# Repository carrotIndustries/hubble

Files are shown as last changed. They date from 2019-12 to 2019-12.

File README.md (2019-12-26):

Hubble is a multitool for SFP(+) transceivers. It can read 
identification and monitoring data using the transceiver's I²C-based 
management interface.

This project is still work in progress.

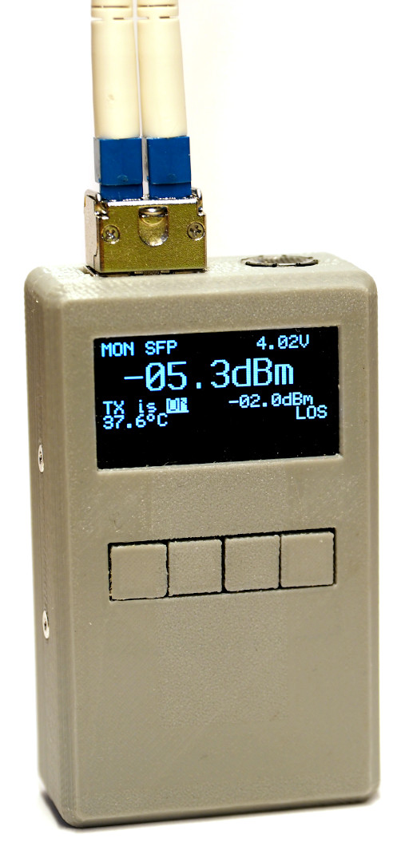
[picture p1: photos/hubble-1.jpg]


# Features and Facts
- Read SFP(+) transceiver identification data
- Optical transceivers
  - turn laser on/off
  - read optical power (RX and TX)
  - read temperature
- 88E111 based 1000 BASE-T transceivers
  - Detect link
  - Count received frames
  - Cable test (TDR) (work in progress)
- (optionally) PRBS generator and eye diagram monitor (work in progress)
- STM32L412 Cortex-M4 MCU
- 128x64 monochrome OLED
- 4 buttons (Mode, Select, Down, Up)
- USB 2.0 Fullspeed for charging and software upgrade
- 14500 Li-Ion battery
- really bright LED flashlight

# Hardware

## Main board

[Schematics](hw/main/output/schematic.pdf)

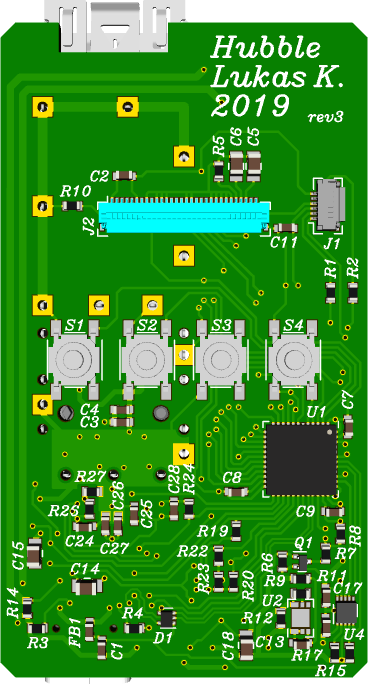
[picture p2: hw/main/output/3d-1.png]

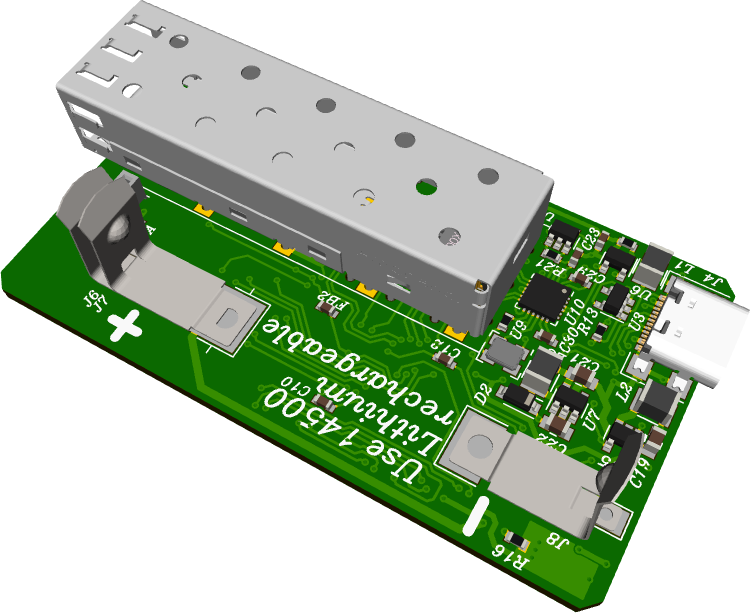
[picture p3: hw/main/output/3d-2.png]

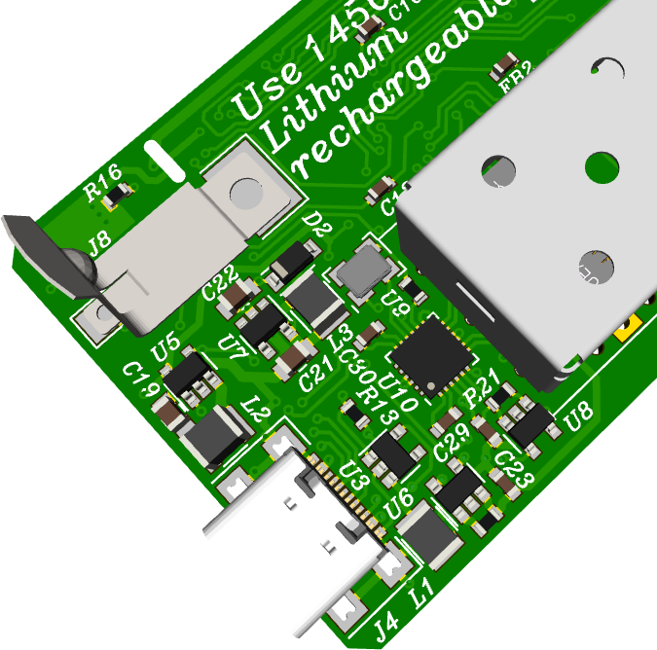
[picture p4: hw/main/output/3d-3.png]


## LED Board

[Schematics](hw/led/output/schematic.pdf)

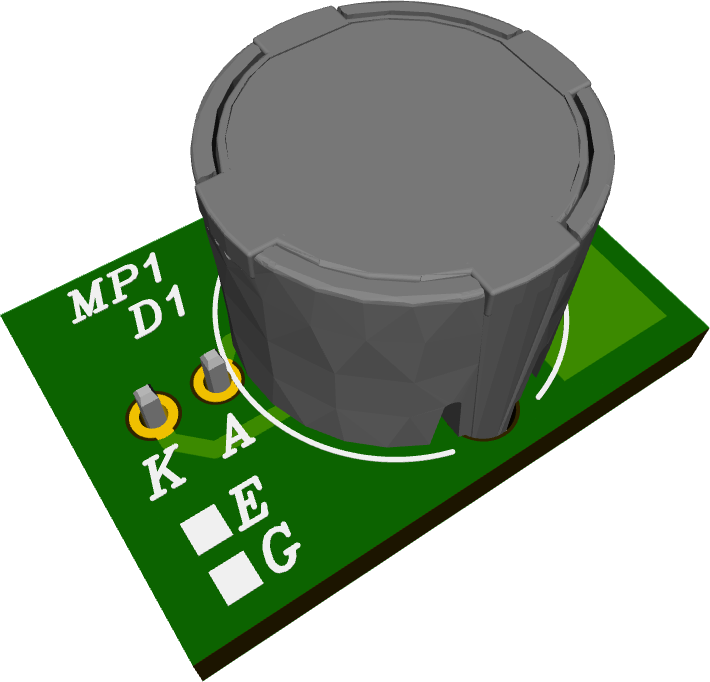
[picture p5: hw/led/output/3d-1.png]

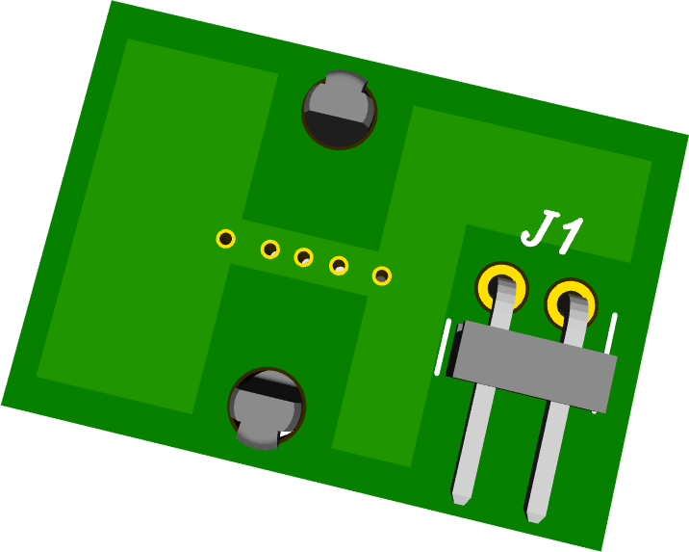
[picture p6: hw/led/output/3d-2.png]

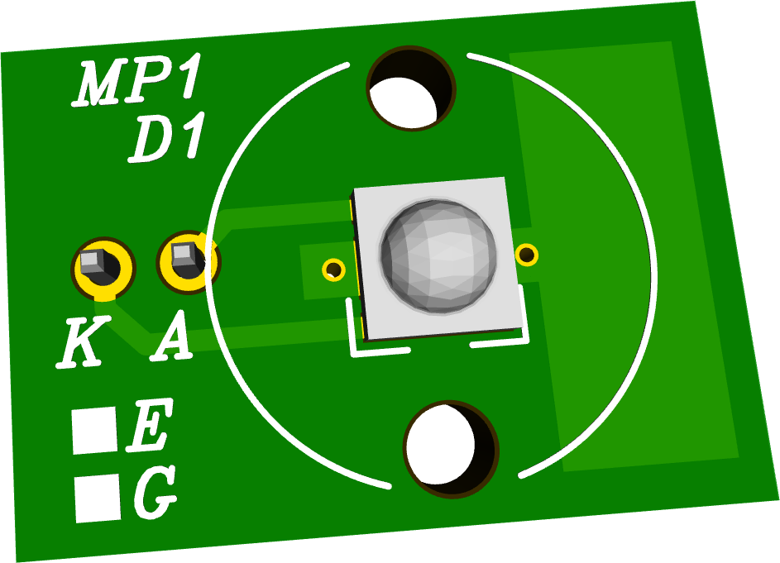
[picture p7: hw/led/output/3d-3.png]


## SWD debug adapter

[Schematics](hw/swd/output/schematic.pdf)

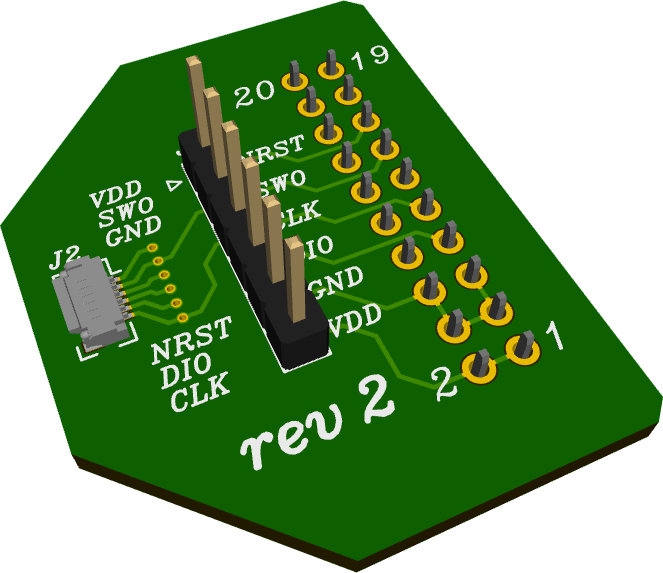
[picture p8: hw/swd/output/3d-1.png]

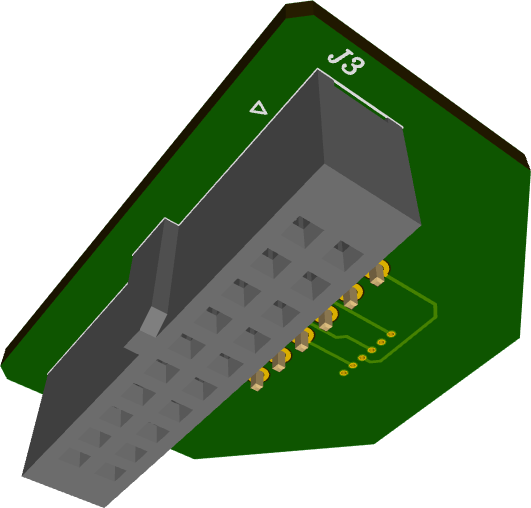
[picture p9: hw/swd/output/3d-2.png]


# Disassembled

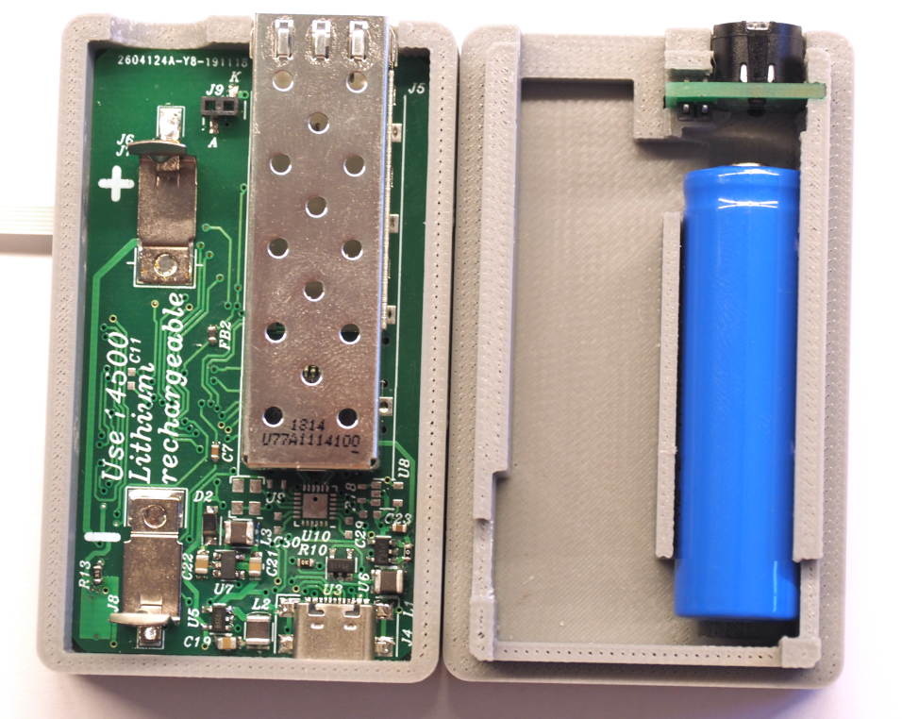
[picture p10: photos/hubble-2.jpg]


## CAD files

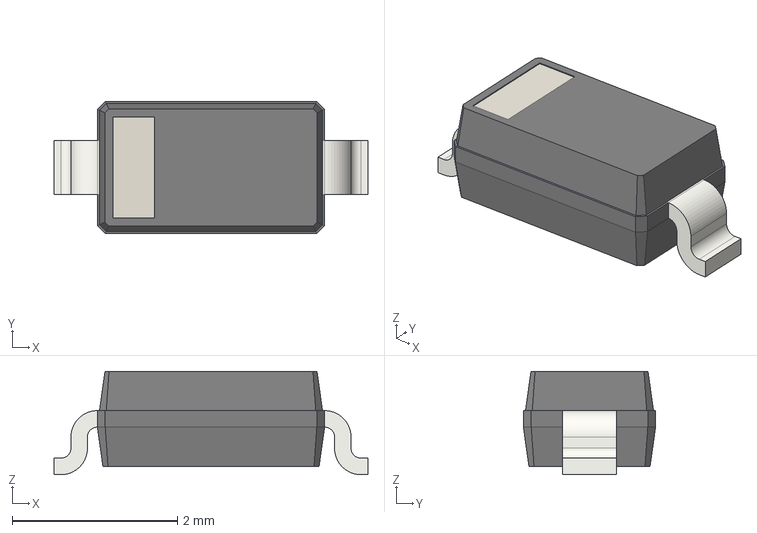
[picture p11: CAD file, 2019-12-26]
hw/main/cache/3d_models/pool_6d752bc3-29b3-45df-8cf2-1e3aacefbcc6/3d_models/diode/D_SOD-123.step
3.80 x 1.60 x 1.25 mm

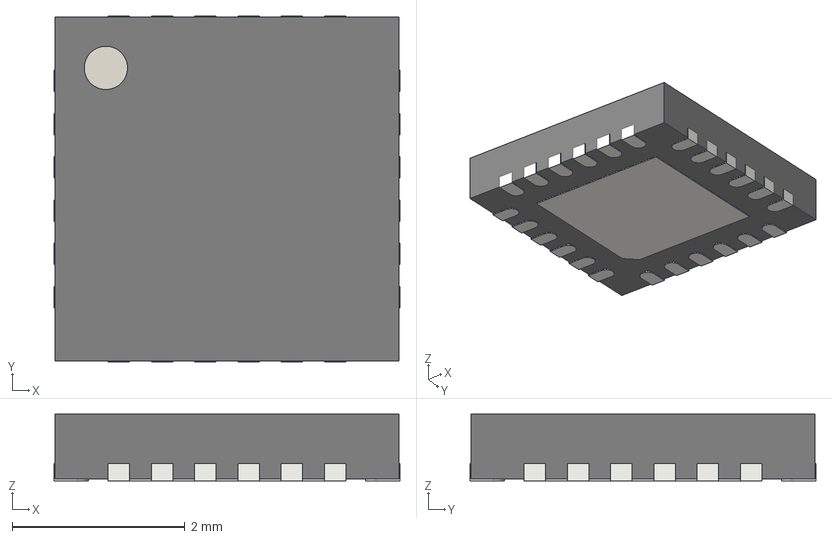
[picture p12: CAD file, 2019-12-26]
hw/main/cache/3d_models/pool_6d752bc3-29b3-45df-8cf2-1e3aacefbcc6/3d_models/ic/qfn/QFN-24-1EP_4x4mm_P0.5mm_EP2.6x2.6mm.step
4.00 x 4.00 x 0.77 mm

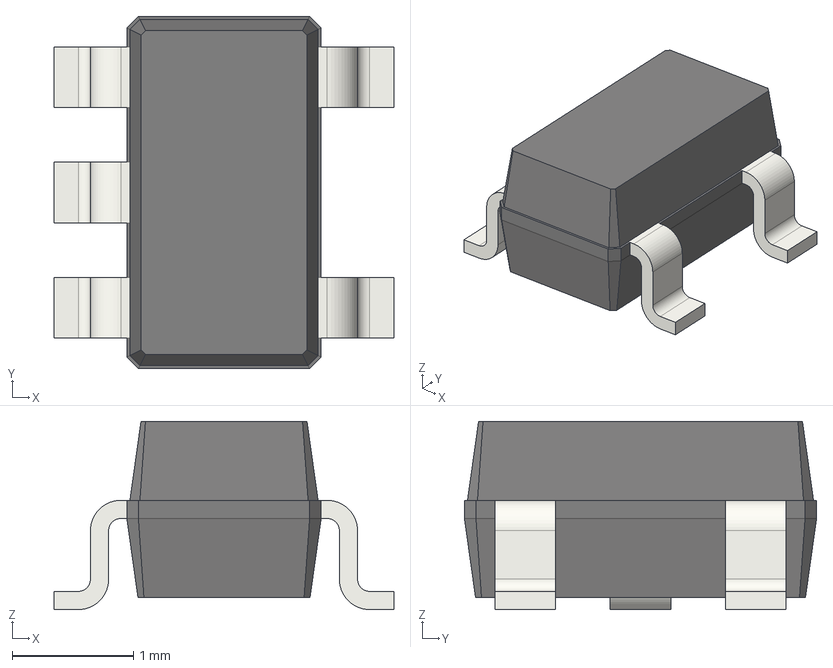
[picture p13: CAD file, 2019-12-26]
hw/main/cache/3d_models/pool_6d752bc3-29b3-45df-8cf2-1e3aacefbcc6/3d_models/ic/so/SOT-23-5.step
2.80 x 2.90 x 1.55 mm

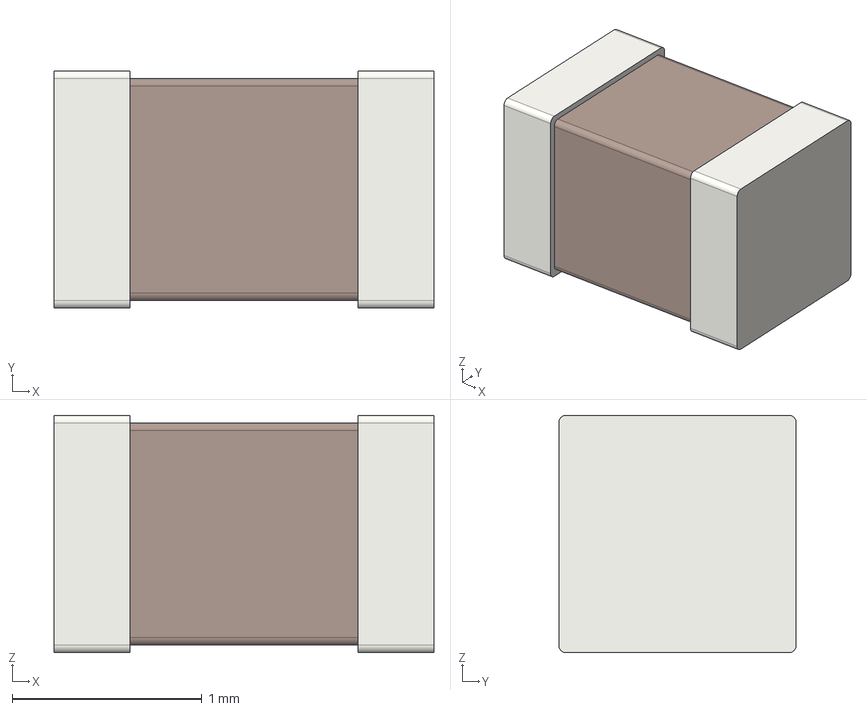
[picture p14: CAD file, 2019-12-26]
hw/main/cache/3d_models/pool_6d752bc3-29b3-45df-8cf2-1e3aacefbcc6/3d_models/passive/capacitor/C_0805_2012Metric.step
2.00 x 1.25 x 1.25 mm

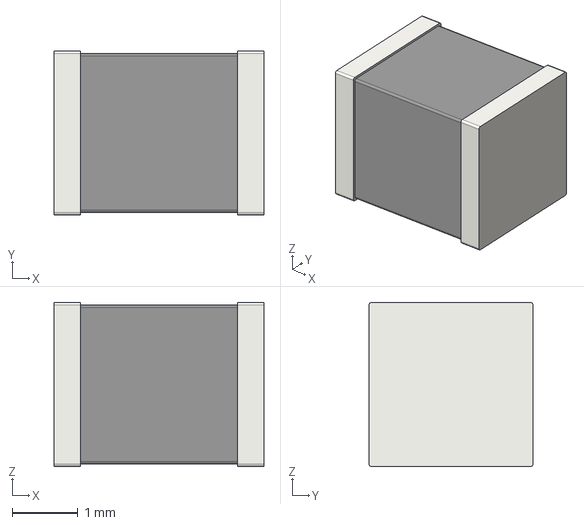
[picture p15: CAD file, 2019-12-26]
hw/main/cache/3d_models/pool_6d752bc3-29b3-45df-8cf2-1e3aacefbcc6/3d_models/passive/inductor/L_1210_3225Metric.step
3.20 x 2.50 x 2.50 mm

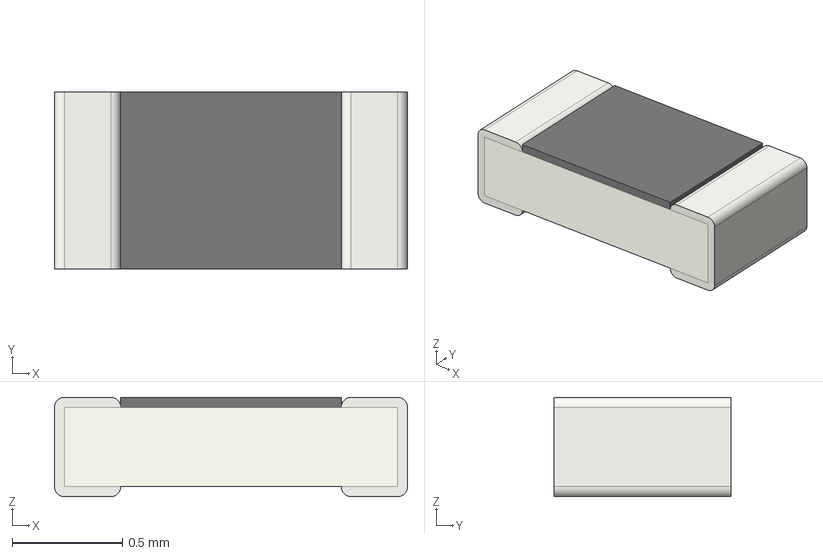
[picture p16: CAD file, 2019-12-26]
hw/main/cache/3d_models/pool_6d752bc3-29b3-45df-8cf2-1e3aacefbcc6/3d_models/passive/resistor/R_0603_1608Metric.step
1.60 x 0.8 x 0.45 mm

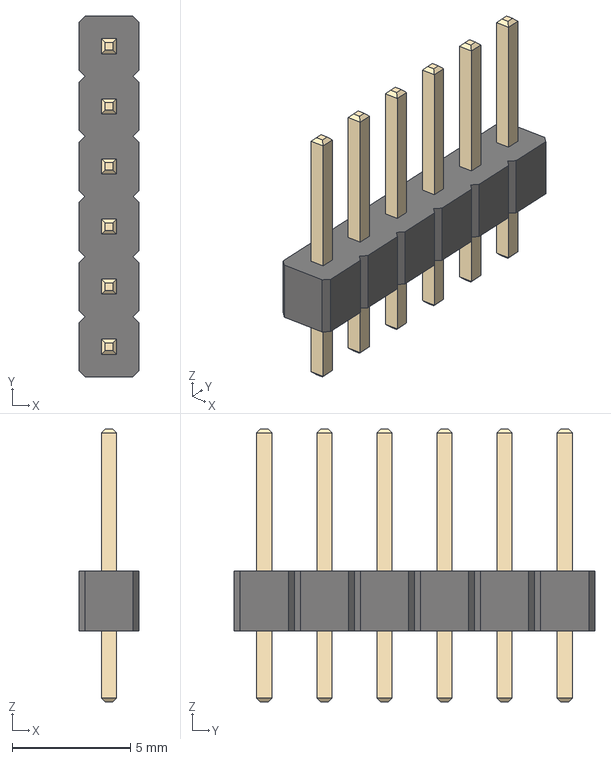
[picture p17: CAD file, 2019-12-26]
hw/swd/cache/3d_models/pool_6d752bc3-29b3-45df-8cf2-1e3aacefbcc6/3d_models/connector/header/2.54mm/PinHeader_1x06_P2.54mm_Vertical.step
2.54 x 15.2 x 11.5 mm

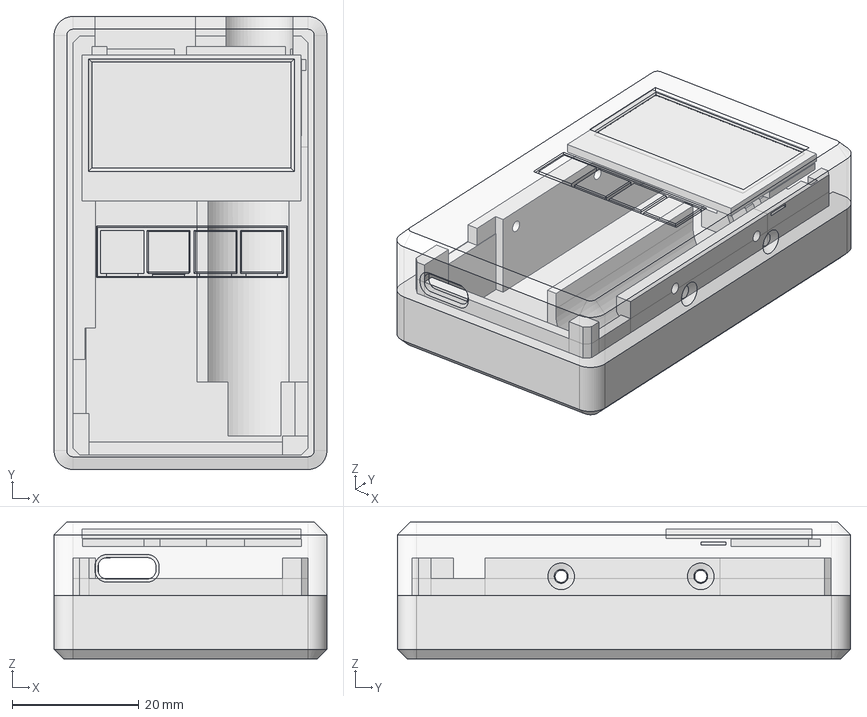
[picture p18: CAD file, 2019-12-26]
mech/hubble.FCStd
43.0 x 71.4 x 21.6 mm
top
oled
bottom
shim

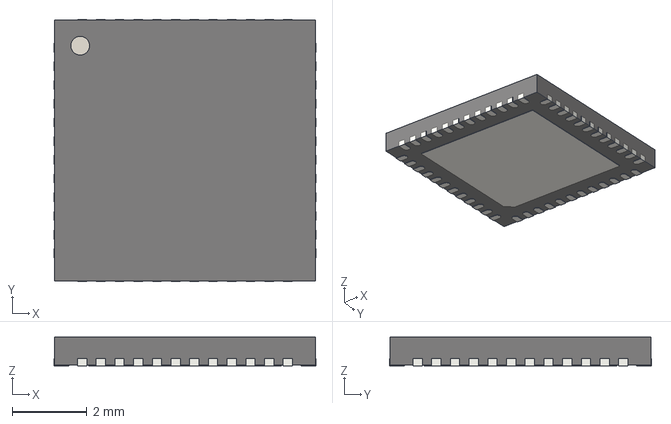
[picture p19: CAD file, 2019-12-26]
hw/main/cache/3d_models/pool_6d752bc3-29b3-45df-8cf2-1e3aacefbcc6/3d_models/ic/qfn/QFN-48-1EP_7x7mm_P0.5mm_EP5.15x5.15mm.step
7.00 x 7.00 x 0.77 mm

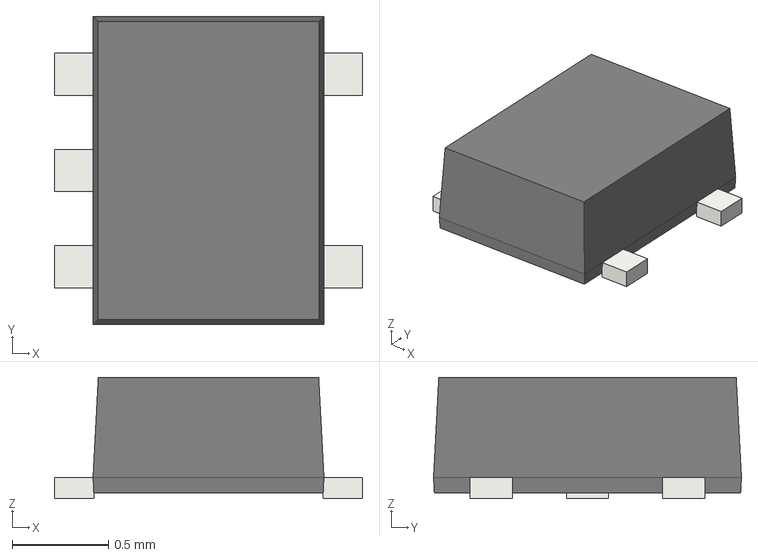
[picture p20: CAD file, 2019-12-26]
hw/main/cache/3d_models/pool_6d752bc3-29b3-45df-8cf2-1e3aacefbcc6/3d_models/ic/so/SOT-553.step
1.60 x 1.60 x 0.63 mm

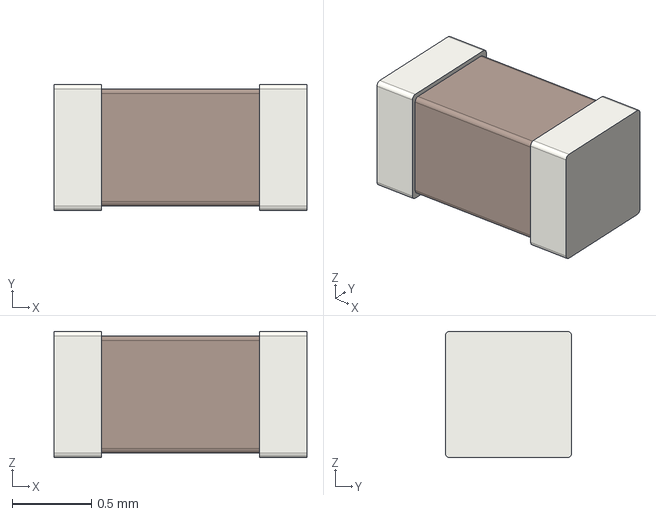
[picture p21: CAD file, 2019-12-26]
hw/main/cache/3d_models/pool_6d752bc3-29b3-45df-8cf2-1e3aacefbcc6/3d_models/passive/capacitor/C_0603_1608Metric.step
1.60 x 0.8 x 0.8 mm

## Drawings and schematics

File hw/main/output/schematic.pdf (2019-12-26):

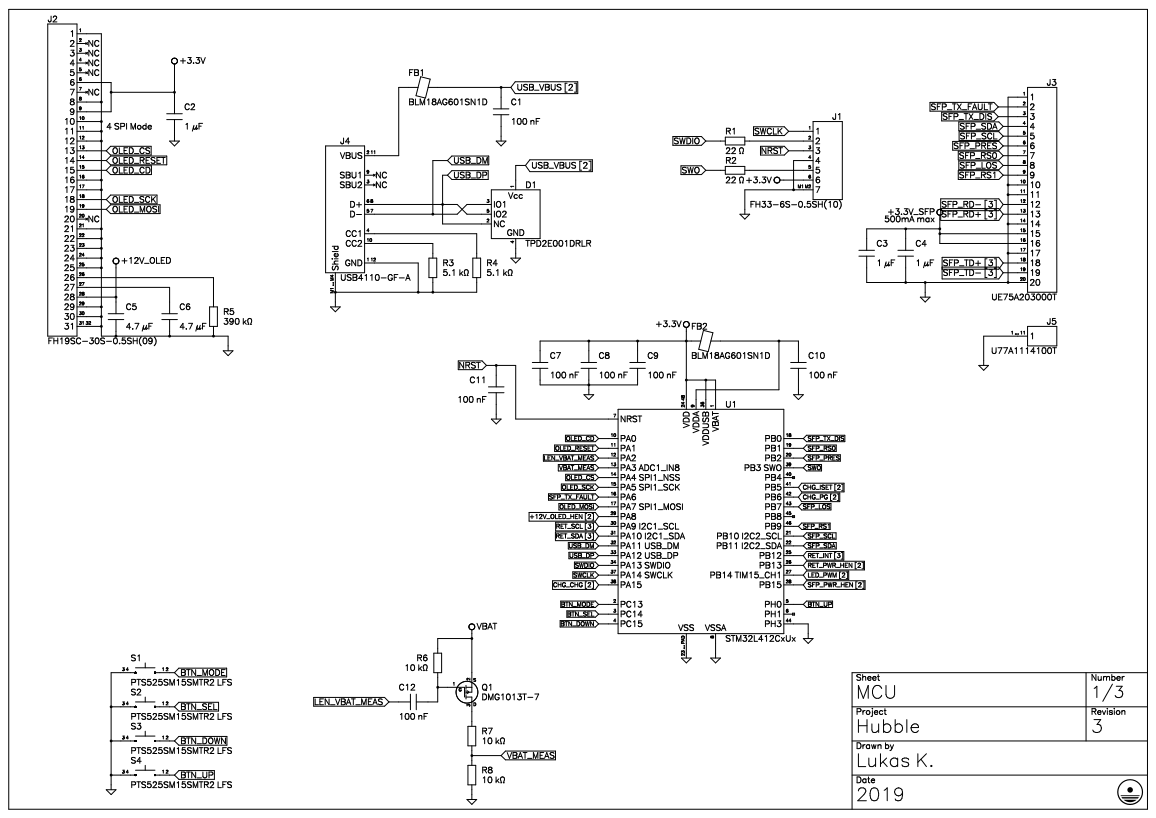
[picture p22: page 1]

Drawn by Lukas K.

Date

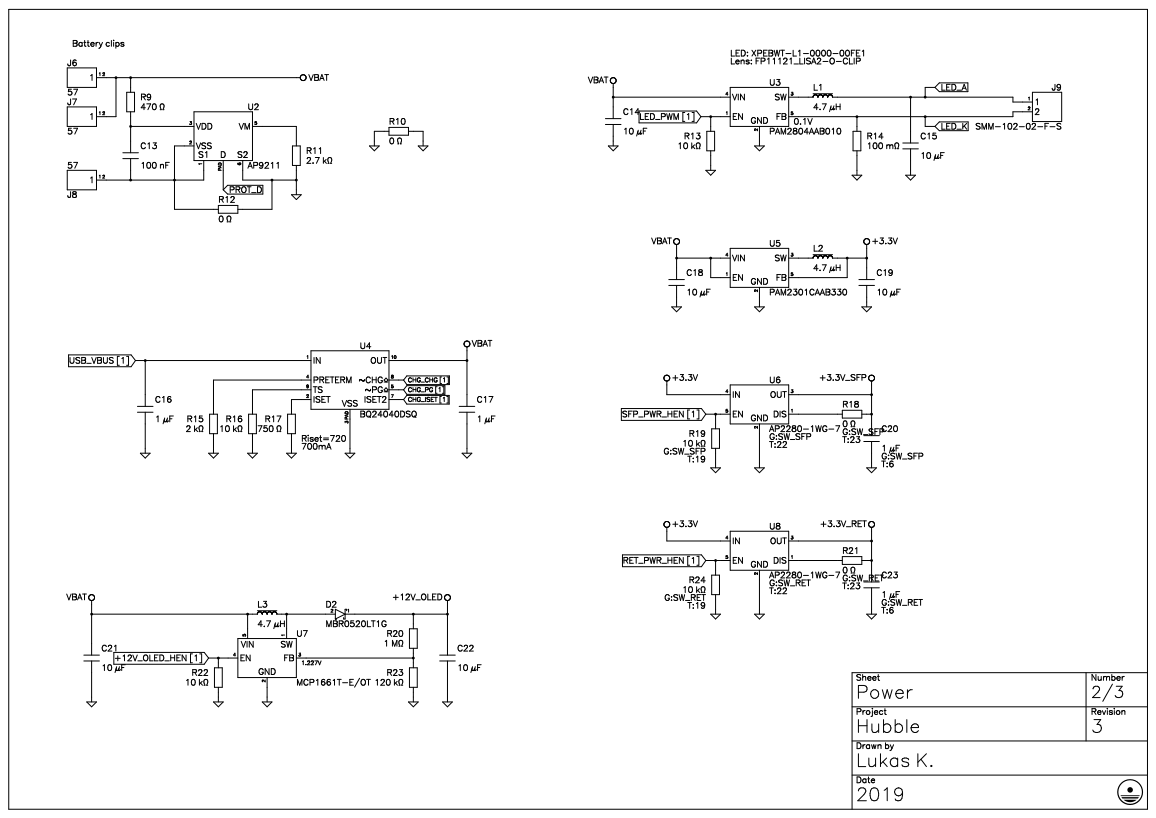
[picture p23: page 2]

GND

Sheet Power | Number 2/3

Project Hubble | | Revision 3

Drawn by

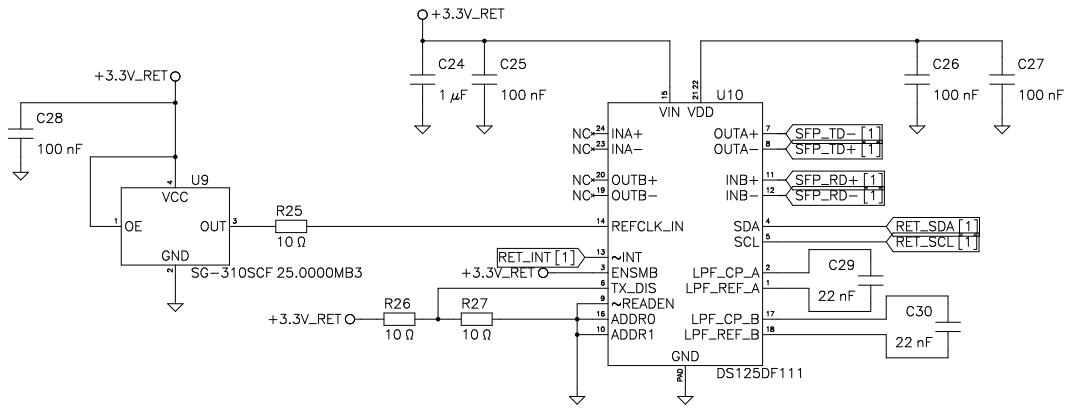
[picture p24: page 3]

RET_SDA [1]
RET_SCL [1]

Sheet Retimer | Number 3/3

Project Hubble | | Revision 3

Drawn by

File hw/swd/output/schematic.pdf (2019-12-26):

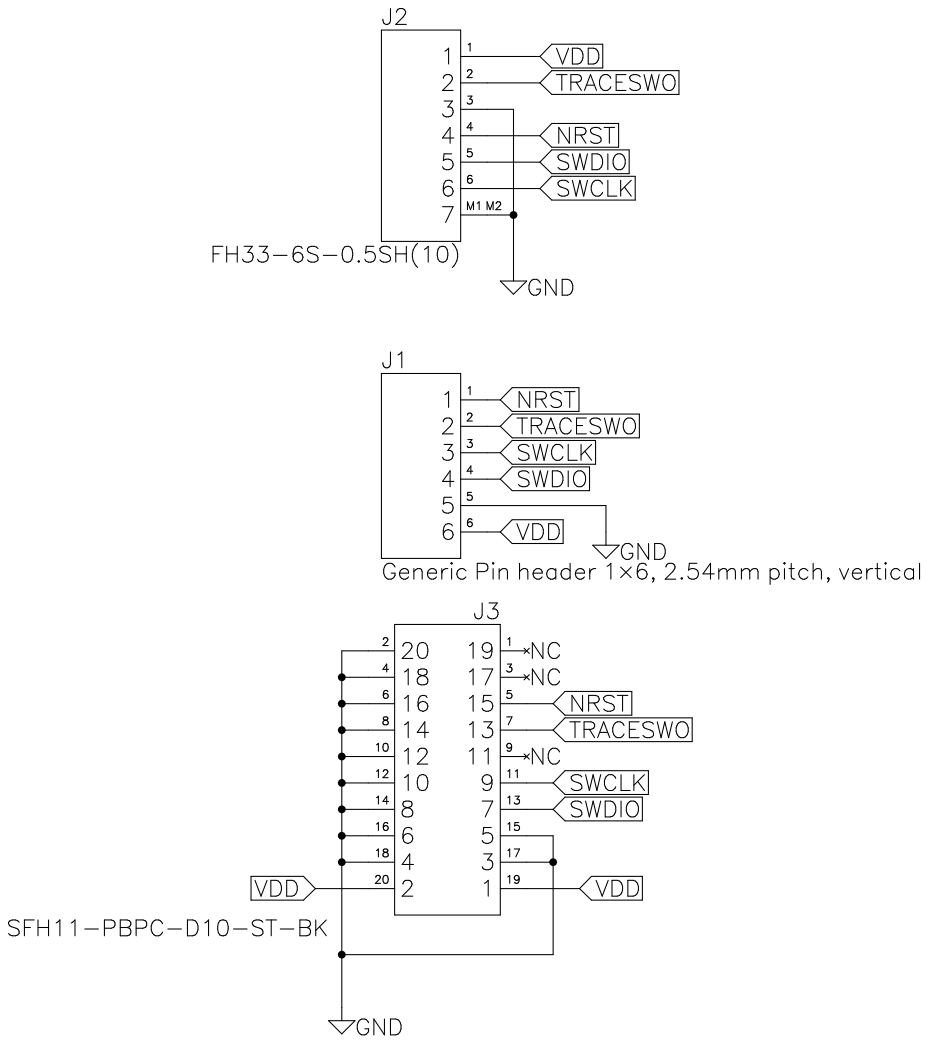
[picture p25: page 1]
Sheet; Number; First sheet; Generic Pin header 1×6, 2.54mm pitch, vertical; VDD; SWDIO; TRACESWO; NRST; SWCLK SWDIO; SWCLK; GND

16 | 15
18 | 17

SFH11-PBPC-D10-ST-BK

Project Hubble SWD Adapter | Revision 2
Drawn by Lukas K.

Date 2019

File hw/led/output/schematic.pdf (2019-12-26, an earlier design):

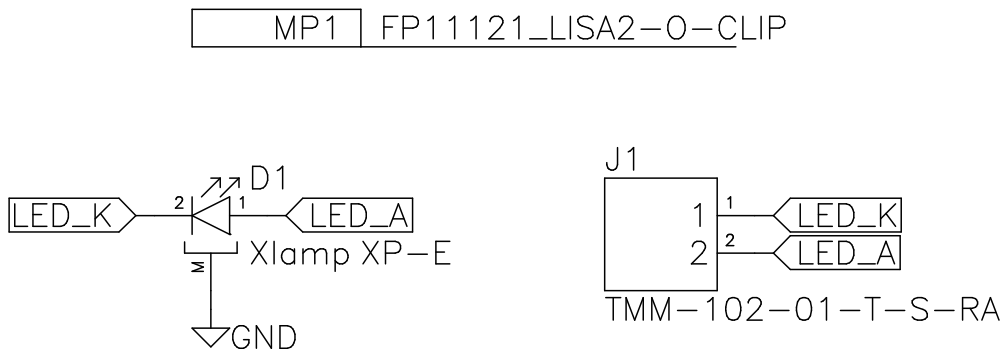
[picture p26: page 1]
Sheet; Number; First sheet; TMM-102-01-T-S-RA; FP11121_LISA2-O-CLIP; Xlamp XP-E; LED_K; LED_A; GND

Project Hubble LED | Revision 1
Drawn by Lukas K.

Date 2019

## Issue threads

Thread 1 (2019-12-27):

[FR] Red light for fiber testing

RichiH, 2019-12-27:
It would be nice if you could optionally add a red light source to test fibers with in the next revision. Ideally with configurable blink patterns in case you test more than one.

9er, 2019-12-27:
We thought about it, but the LED (which is stupidly bright) won. Problem with a light source is that you need a connector, and of course the light source and lens and everything.

Maybe you could mod an old SFP with a red laser? Or is something like that already on the market maybe?

RichiH, 2019-12-27:
If we can get a certain volume going, I am pretty certain we can make a drop shipment of pre-assembled things from China work at little cost; problem would be coordination between everyone interested in those.

9er, 2019-12-27:
That would be pretty cool. Volume will most certainly be an issue. Also the laser source: I've never seen a TOSA-style red light laser, and also, the required 5-10 dBm might be an issue.

Not sure if this is worth it, since you can just buy a cheap fiber fault finder for ~10 bucks. One more thing to carry around tho.

RichiH, 2020-01-09:
Agreed, this is not about cost, it's about one-tool-for-ALL-the-things.

carrotIndustries, 2020-01-09:
To me as well, the fiber fault finder in an SFP form factor seems like the more sensible approach as this keeps the main unit itself nice and small.

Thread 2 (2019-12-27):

[proposed] encode programmable SFPs

sxpert, 2019-12-27:
certain SFPs are programmable to allow them to be accepted by certain switches. would be great to have a feature to program the proper values

9er, 2019-12-27:
This is something we thought about, but never focused on. There are a few things to figure out:
 - can a given transceiver be configured? I've heard that some transceivers will tilt if you don't know the magic cheat code
 - what are "the proper values" for a given transceiver and a given "goal"
 - possible legal issues (I know that some HW manufacturers really don't like this...)

Hubble has a USB-C port for charging, but also Virtual COM port. So you could have a program that writes memory dumps onto the SFP and you could store them on your computer. We don't have much experience on how you'd flash an SFP (addresses, passwords?, values, etc.), so we'd need quite some help to implement this.

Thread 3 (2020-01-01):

[req] BOM

VitMain, 2020-01-01:
Hello!

Could you please share BOM with Mouser and Digikey part numbers or links where to buy the parts?

Thank you!

NeoFromMatrix, 2024-12-31:
just exported with 2.6.0
[led.csv](https://github.com/user-attachments/files/18280662/led.csv)
[main.csv](https://github.com/user-attachments/files/18280663/main.csv)
[swd.csv](https://github.com/user-attachments/files/18280664/swd.csv)

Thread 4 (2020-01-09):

[FR] Bluetooth/Wifi connectivity

RichiH, 2020-01-09:
This is more of a long-term FR.

Using a board with wireless connectivity would allow for ongoing, remote measurements.

carrotIndustries, 2020-01-09:
TBH, I don't have any plans on evolving this project significantly beyond it's current set of features hardware-wise.

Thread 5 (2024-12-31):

Request to buy populated PCB

jfsgithub2020, 2024-12-31:
Hi Lukas,

I am very much interested in buying a populated PCB - the assembly, I can do by myself. Any chance, that you have some still or that enough interest is there to get a group order together at some full feature supplier?

I saw the report on heise about "Hubble" and loved it on sight.

Thx
Jocki

Kreijstal, 2024-12-31:
worst case situation we can do one for community, where we order on bulk for discount but somehow has to handle the shipping

jfsgithub2020, 2024-12-31:
I would be happy to organize a collective order, if get someone to review what I need to do and recommend where to place the order. As Lukas has already made one sample (ormore?), he could give advice.

NeoFromMatrix, 2024-12-31:
I've already ordered a 5 sets of PCBs at jlcpcb (main, led and debug), so I could offer probably  2-4 unpopulated sets (shipping from Austria).

The component situation/BOM is rather tough;

1. Some components are EOL/no longer available at Mouser.  So I need to check if I can find a drop-in replacement. (e.g. PAM2301CAAB330 or the pushbuttons)
2. With some I'm missing an explicit MPN (like the AP9211 which is available in multiple variants). Needs further clarification, maybe any of the options work.
3. Some parts are missing in the BOMs I've exported via Horizon (e.g. Lithium cell type or requirements, mechanical parts like screws or nuts, OLED!)
4. Some parts are quite expensive (e.g. DS125DF111 re-timer, 15€). I'd expect the parts for one unit to be  like 45€ before tax (not including the OLED and LI-ION cell).
5. There is no real documentation on the software (how to compile and flash it, altough it's probably self explanatory after digging for some time (looks like a custom bootloader and an app with an added signature).

(this is a really incomplete list!)

I'll write up all the open points I've found and maybe we can collectively solve it.
One side effect. If this gains more traction maybe someone looks into how coding optics works (like FS and FlexOptix) and writes software for it.

I don't want to put any stress on Lukas, just want to say I'm grateful he open sourced it! :)

Kreijstal, 2024-12-31:
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

if you succeed please fork and document your changes, of course try to upstream if the owner approves, but we can always have the source from some source :)

NeoFromMatrix, 2024-12-31:
Just noticed I've ordered R3 from the master branch, not rev3-wip. They differ slightly (e.g. R26, R27 on Retimer sheet).
Maybe Lukas knows what version he got working or if he needed any other fixes.

Tragen, 2025-01-01:
I would be interested to get a set if you order it.

NeoFromMatrix, 2025-01-18:
For all who want to try to build a couple units or help at the process of creating build instruction:

I can offer **two** sets of bare PCBs at cost of 5€ + shipping from Austria (via Post.at -> Eco-Päckchen S/Versandtasche, not as Eco-Brief S/Envelope)

Each set consists of; (as shown at the picture below)
1x SWD PCB
1x LE PCB
1x rev2 main PCB (from master branch -> gerber.zip)
1x rev3 main PCB (from rev3-wip branch -> gerber.zip)

(The rev2 main PCB is probably not interesting as the PAM2301CAAB330 is no longer available unless you find a drop-in replacement)

PCBs are from JLCPCB, 1.6mm thick, HAL surface finish

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

If you want one set, write me an mail github-hubble-pcb(a)pfeffer.link

Maybe we should also continue our efforts here: https://github.com/NeoFromMatrix/hubble

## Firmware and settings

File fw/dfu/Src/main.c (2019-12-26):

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

/* Includes ------------------------------------------------------------------*/
#include "main.h"
#include "usb_device.h"

/* USER CODE BEGIN Includes */
#include "dpy_trg.h"
#include "common/dpy.h"
#include "usbd_core.h"
#include "usbd_dfu_if.h"
#include "version_info.h"
/* USER CODE END Includes */

CRC_HandleTypeDef hcrc;

SPI_HandleTypeDef hspi1;

/* USER CODE BEGIN PV */
static const version_info_t *version_info = (void*)(0x80051a0);
/* USER CODE END PV */

void SystemClock_Config(void);
static void MX_GPIO_Init(void);
static void MX_SPI1_Init(void);
static void MX_CRC_Init(void);
/* USER CODE BEGIN 0 */
typedef  void (*pFunction)(void);
pFunction JumpToApplication;
uint32_t JumpAddress;

uint8_t app_is_valid() {
	return ((*(__IO uint32_t*)USBD_DFU_APP_DEFAULT_ADD) & 0x2FFE0000 ) == 0x20000000 && version_info->sig == VERSION_INFO_SIG && version_info->len > 0;
}

extern USBD_HandleTypeDef hUsbDeviceFS;

static void enter_app() {
	if(app_is_valid())
    {
		USBD_Stop(&hUsbDeviceFS);
		USBD_DeInit(&hUsbDeviceFS);
		HAL_Delay(100);
	   SysTick->CTRL = 0;
	   HAL_NVIC_DisableIRQ(SysTick_IRQn);
	   HAL_NVIC_DisableIRQ(USB_IRQn);

      /* Jump to user application */
      JumpAddress = *(__IO uint32_t*) (USBD_DFU_APP_DEFAULT_ADD + 4);
      JumpToApplication = (pFunction) JumpAddress;

      /* Initialize user application's Stack Pointer */
      __set_MSP(*(__IO uint32_t*) USBD_DFU_APP_DEFAULT_ADD);
      JumpToApplication();
      while(1)
		   ;
    }

}


/* USER CODE END 0 */

/**
  * @brief  The application entry point.
  * @retval int
  */
int main(void)
{
  

  /* MCU Configuration--------------------------------------------------------*/

  /* Reset of all peripherals, Initializes the Flash interface and the Systick. */
  HAL_Init();

  /* Configure the system clock */
  SystemClock_Config();

  /* USER CODE BEGIN SysInit */
  HAL_InitTick(TICK_INT_PRIORITY);
  /* USER CODE END SysInit */

  /* Initialize all configured peripherals */
  MX_GPIO_Init();
  MX_USB_DEVICE_Init();
  MX_SPI1_Init();
  MX_CRC_Init();
  /* USER CODE BEGIN 2 */

  dpy_trg_init(&hspi1);
  HAL_GPIO_WritePin(LED_HEN_GPIO_Port, LED_HEN_Pin, 1);
  HAL_Delay(50);
  HAL_GPIO_WritePin(LED_HEN_GPIO_Port, LED_HEN_Pin, 0);

  uint16_t boot_timeout = 4000;
  uint8_t autoboot = 1;

  /* USER CODE END 2 */

  /* Infinite loop */
  /* USER CODE BEGIN WHILE */
  while (1)
  {
	  dpy_clear();
	  dpy_puts(0,0,"- Hubble Bootloader -");
	  if(app_is_valid()) {
		  dpy_puts(0,16, "App is valid");
		  dpy_puts(0,24, "press mode to boot");
		  dpy_puts(0, 56, version_info->desc);
		  if(HAL_GPIO_ReadPin(BTN_MODE_GPIO_Port, BTN_MODE_Pin) == 0) {
			  dpy_clear();
			  const uint32_t *crc_from_flash = (void*)(USBD_DFU_APP_DEFAULT_ADD+version_info->len);
			  dpy_puts(0,0,"Flash");
			  dpy_putix(36,0,8,*crc_from_flash);
			  dpy_trg_flush();
			  uint32_t crc_calc = HAL_CRC_Calculate(&hcrc, (void*)USBD_DFU_APP_DEFAULT_ADD, version_info->len);
			  dpy_puts(0,8,"Calc.");
			  dpy_putix(36,8,8,crc_calc);
			  if(crc_calc == *crc_from_flash) {
				  dpy_puts(0,24,"CRC okay");
				  dpy_trg_flush();
				  HAL_Delay(200);
			  }
			  dpy_trg_flush();
			  if(crc_calc != *crc_from_flash) {
				  dpy_puts(0,24,"CRC Mismatch");
				  dpy_trg_flush();
				  HAL_Delay(2000);
				  while(HAL_GPIO_ReadPin(BTN_MODE_GPIO_Port, BTN_MODE_Pin) == 0)
					  ;
			  }
			  else {
				  while(HAL_GPIO_ReadPin(BTN_MODE_GPIO_Port, BTN_MODE_Pin) == 0)
					  ;
				  enter_app();
			  }


		  }
		  /*if(autoboot) {
			  dpy_puts(0, 24, "Starting app in");
			  dpy_puti(16*6, 24, 2, (boot_timeout-HAL_GetTick())/1000);
			  if(HAL_GPIO_ReadPin(BTN_MODE_GPIO_Port, BTN_MODE_Pin) == 0) {
				  autoboot = 0;
			  }
			  if(HAL_GetTick()>=boot_timeout) {
				  enter_app();
			  }
		  }
		  else {
			  dpy_puts(0, 24, "Autoboot cancelled");
		  }
		  if(HAL_GPIO_ReadPin(BTN_SEL_GPIO_Port, BTN_SEL_Pin) == 0) {
			  enter_app();
		  }*/


	  }
	  else  {
		  //autoboot = 0;
		  dpy_puts(0,16, "App is invalid");
	  }
	  switch(dfu_status) {
	  case DFU_STATUS_IDLE:
		dpy_puts(0, 40, "Idle");
		break;

	  case DFU_STATUS_WRITE:
		dpy_puts(0, 40, "Write");
		break;

	  case DFU_STATUS_ERASE:
		dpy_puts(0, 40, "Erase");
		break;
	  }
	  dpy_puts(6*6, 40, "0x");
	  dpy_putix(8*6, 40, 8, dfu_current_address);

	  //dpy_puti(64, 8, 5, HAL_GetTick()/1000);
	  dpy_trg_flush();
    /* USER CODE END WHILE */

    /* USER CODE BEGIN 3 */
  }
  /* USER CODE END 3 */
}

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


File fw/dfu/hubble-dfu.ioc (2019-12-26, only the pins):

Mcu.UserName=STM32L412CBUx
PA0.GPIO_Label=OLED_CD
PA0.Signal=GPIO_Output
PA1.GPIO_Label=OLED_RESET
PA1.Signal=GPIO_Output
PA11.Signal=USB_DM
PA12.Signal=USB_DP
PA4.Signal=SPI1_NSS
PA5.Signal=SPI1_SCK
PA7.Signal=SPI1_MOSI
PA8.GPIO_Label=P12V_OLED_HEN
PA8.Signal=GPIO_Output
PB14.GPIO_Label=LED_HEN
PB14.Signal=GPIO_Output
PC13.GPIO_Label=BTN_MODE
PC13.Signal=GPIO_Input

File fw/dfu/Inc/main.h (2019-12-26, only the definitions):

#define BTN_MODE_Pin GPIO_PIN_13
#define BTN_MODE_GPIO_Port GPIOC
#define BTN_SEL_Pin GPIO_PIN_14
#define BTN_SEL_GPIO_Port GPIOC
#define OLED_CD_Pin GPIO_PIN_0
#define OLED_CD_GPIO_Port GPIOA
#define OLED_RESET_Pin GPIO_PIN_1
#define OLED_RESET_GPIO_Port GPIOA
#define LED_HEN_Pin GPIO_PIN_14
#define LED_HEN_GPIO_Port GPIOB
#define P12V_OLED_HEN_Pin GPIO_PIN_8
#define P12V_OLED_HEN_GPIO_Port GPIOA

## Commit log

2019-12-26 add swd adapter rev2
    [PinHeader_1x06_P2.54mm_Vertical.step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]
2019-12-26 add led board
    [hubble-led.gbl, hubble-led.gbo, hubble-led.gbp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]
2019-12-26 led board rev2
    [hubble-led.gko, hubble-led.gto]
2019-12-26 add main board rev2
    [C_0603_1608Metric.step, C_0805_2012Metric.step, D_SOD-123.step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]
2019-12-26 main board rev3
2019-12-26 add case
    [hubble.FCStd]
2020-02-15 long press up to turn on LED

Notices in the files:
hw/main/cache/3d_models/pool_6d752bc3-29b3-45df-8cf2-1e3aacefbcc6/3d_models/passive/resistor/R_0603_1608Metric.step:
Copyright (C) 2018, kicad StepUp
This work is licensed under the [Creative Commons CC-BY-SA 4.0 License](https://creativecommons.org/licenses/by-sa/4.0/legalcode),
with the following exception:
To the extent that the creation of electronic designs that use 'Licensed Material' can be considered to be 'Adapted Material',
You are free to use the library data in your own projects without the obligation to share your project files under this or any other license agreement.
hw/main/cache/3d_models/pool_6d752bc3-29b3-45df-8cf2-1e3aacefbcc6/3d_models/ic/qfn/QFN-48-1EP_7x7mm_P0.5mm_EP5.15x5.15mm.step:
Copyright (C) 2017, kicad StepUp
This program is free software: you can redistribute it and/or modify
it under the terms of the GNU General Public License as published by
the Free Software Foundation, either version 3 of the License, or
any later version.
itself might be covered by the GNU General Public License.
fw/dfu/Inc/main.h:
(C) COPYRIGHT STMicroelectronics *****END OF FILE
